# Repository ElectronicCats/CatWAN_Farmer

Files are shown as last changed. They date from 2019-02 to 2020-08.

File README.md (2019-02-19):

# CatWAN Farmer by Electronic Cats

CatWAN Farmer, a grower's water saving project

Monitoring soil moisture at different depths to determine when to irrigate, and - more importantly - how much water is needed. Save 25%!

## Main characteristics

- Provide low cost, easy to build, and rugged components for optimizing agricultural irrigation.
- DIY calibrated gypsum soil moisture sensors (Watermark SS200 is also supported).
- Hand held sensor reader (soil moisture, soil/water salinity, water pressure).
- Solar powered remote sensor platform.
- 4 electrically separated inputs for soil moisture sensors.
- LoRa module for long range (6 miles).
- temperature/humidity sensors.
- Solar battery charger.
- Real time clock for sleep mode power saving and precise irrigation timing.
- Gateway to connect multiple LoRa end nodes to the Internet.
- Supports packet mode LoRa® (package mode) or LoRaWAN ™ Class A, B and C.
- Compatible with Beelan, The Things Network and other LoRaWAN networks.
- Easy reprogramming compatible with Arduino and Circuit Python.

## Specifications

- 32-bit ARM Cortex-M0+ processor with 256KB flash, 32KB SRAM, and an operating speed of up to 48MHz. 
- Connectivity: USB 2.1.
- Vin: 4.2V-6.0V for charger - otherwise 3.5V-6.0V
- VBATT: 3.7V Lipo
- VCC: 600mA @3.3V
- Receiver Sensitivity: down to -146 dBm.
- TX Power: adjustable up to +18.5 dBm.
- Range: up to 15 km coverage in suburban and up to 5 km coverage.
- Watermark SS200 soil water tension sensor (4 x).
- Capacitive (FDR) volumetric soil moisture sensors (3x).
- Temperature and humidity.
- Compatible LoRa 915 and 868 Mhz.

## LICENSE

Hardware released under an CERN Open Hardware Licence v1.2. See the LICENSE_HARDWARE file for more information.

Designed by Electronic Cats.

Electronic Cats is a registered trademark, please do not use if you sell these PCBs.

Electronic Cats invests time and resources providing this open source design, please support Electronic Cats and open-source hardware by purchasing products from Electronic Cats!

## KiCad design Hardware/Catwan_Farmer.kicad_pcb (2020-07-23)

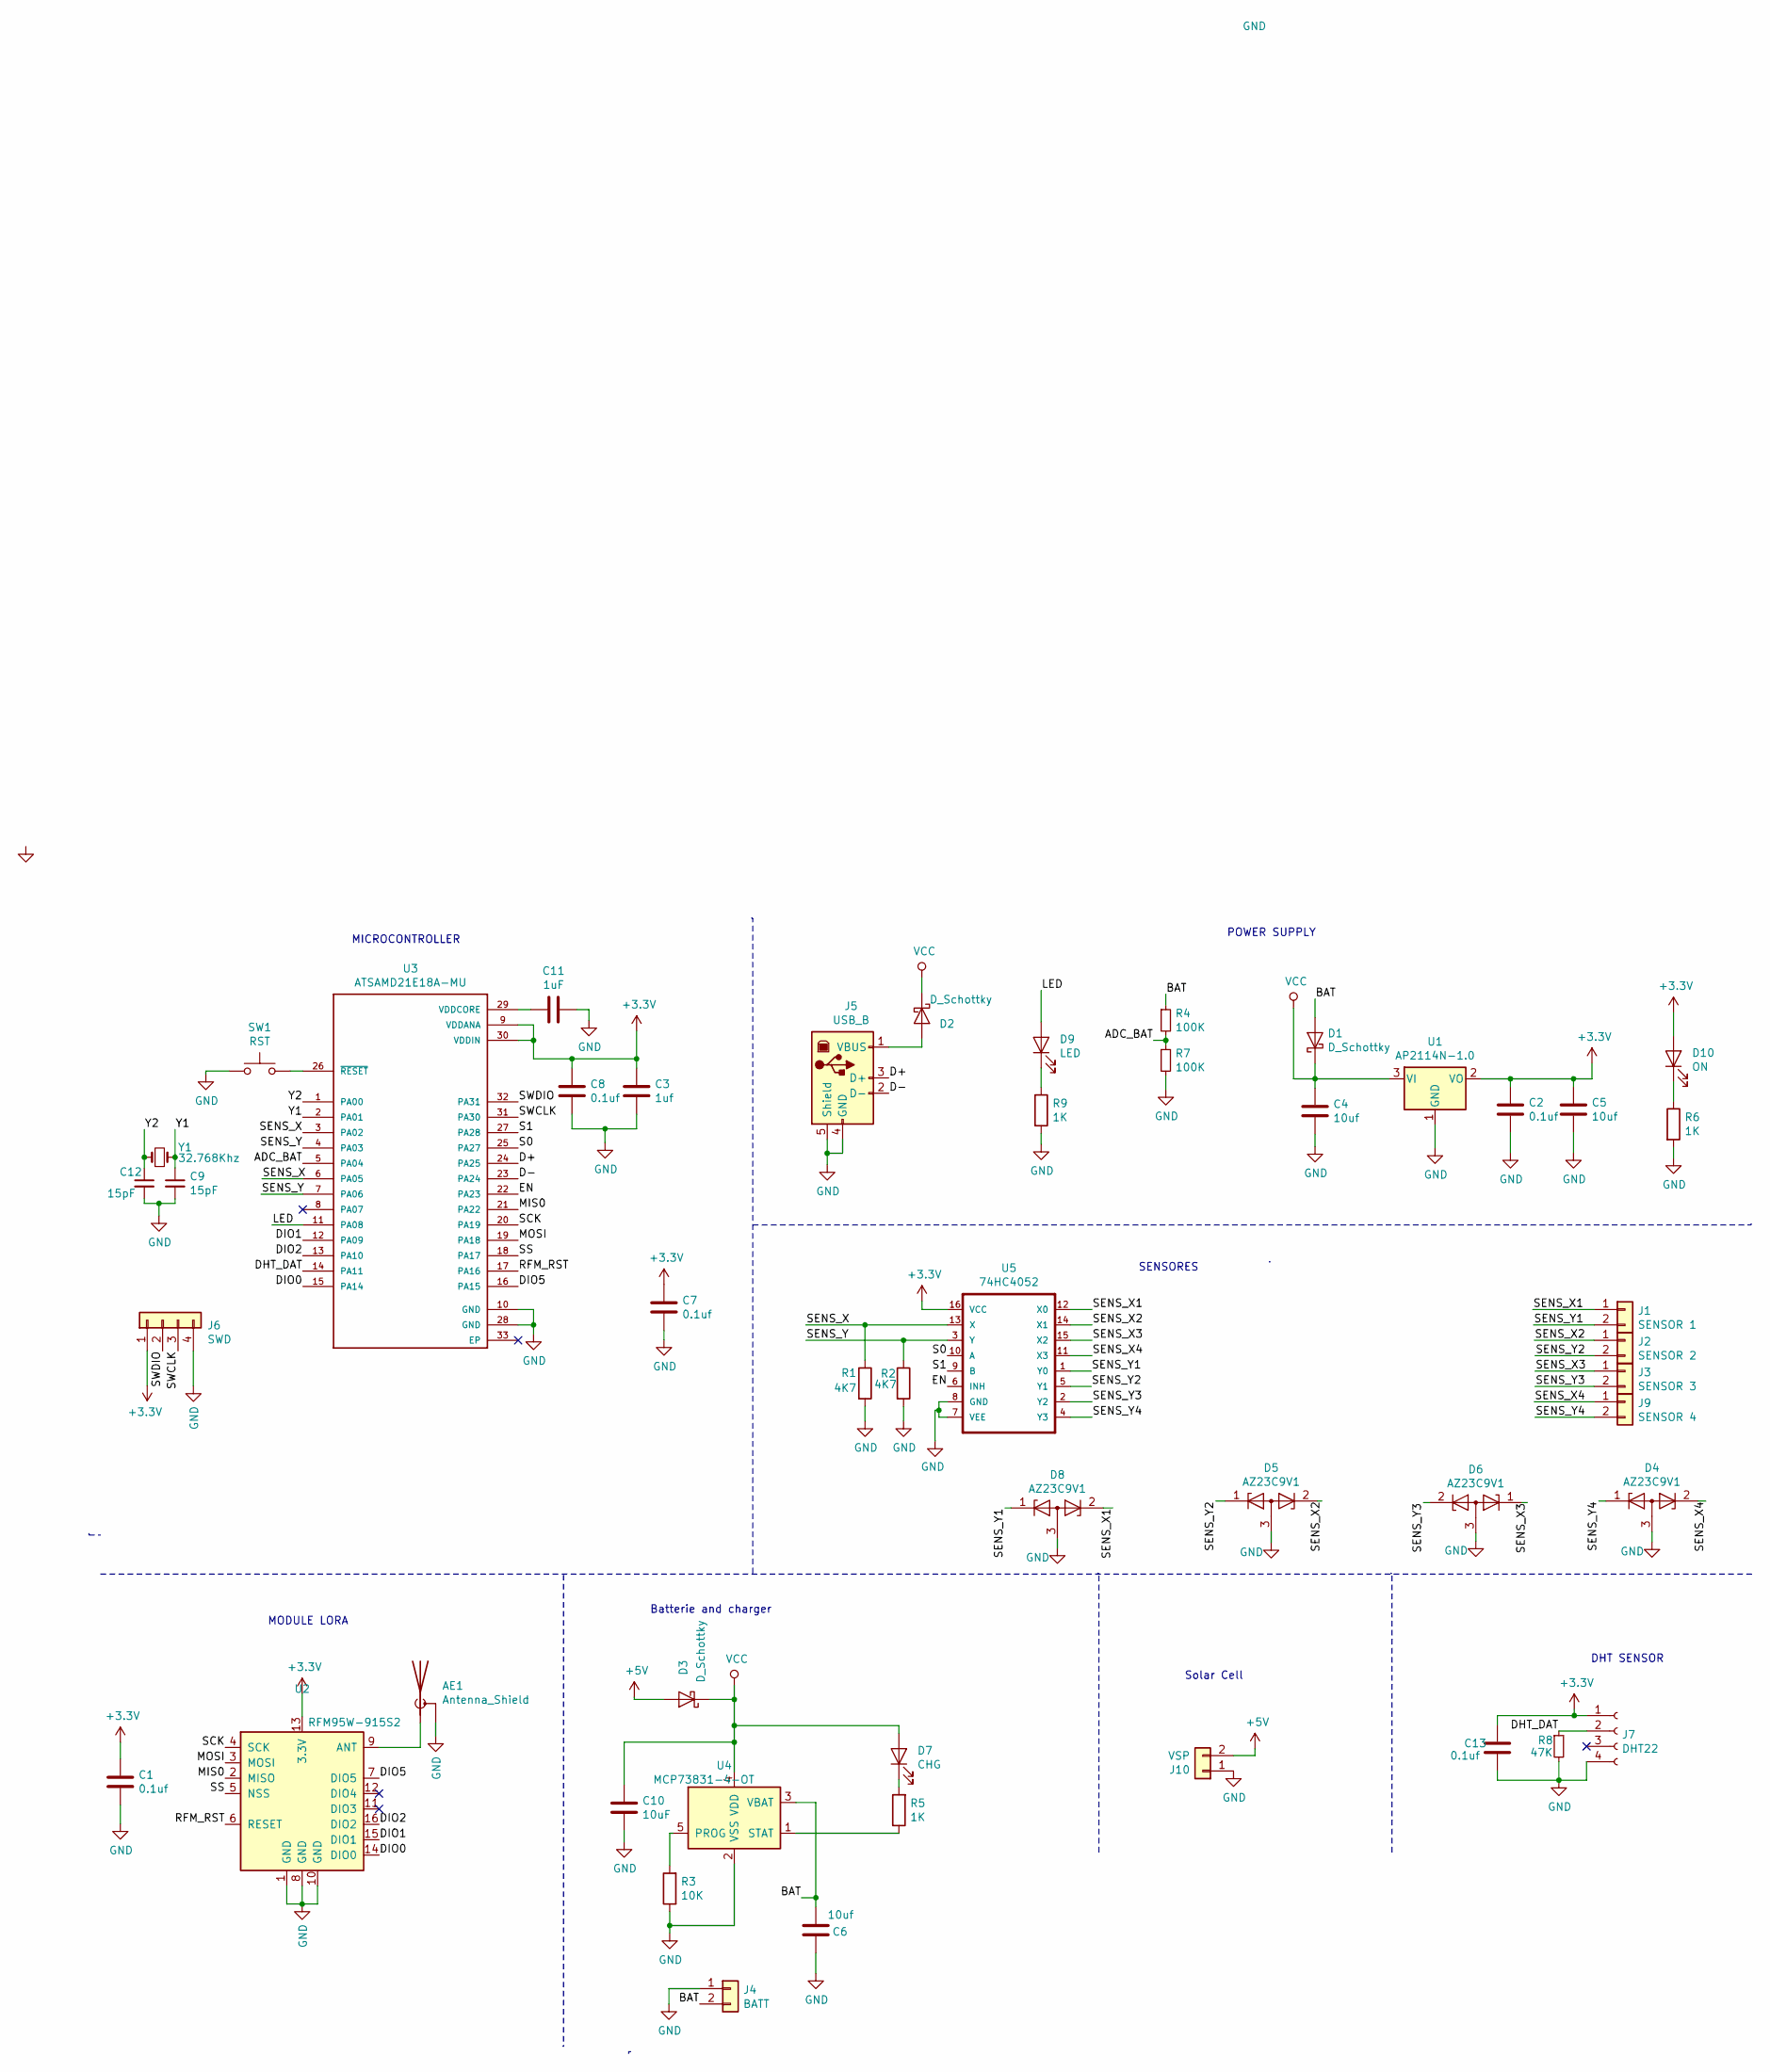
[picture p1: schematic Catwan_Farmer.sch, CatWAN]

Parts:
AE1: Antenna_Shield; AMPHENOL_901-144
C1, C2, C7, C8, C13: 0.1uf; C_0805_2012Metric_Pad1.15x1.40mm_HandSolder
C3: 1uf; C_0805_2012Metric_Pad1.15x1.40mm_HandSolder
C4, C5, C6: 10uf; C_0805_2012Metric_Pad1.15x1.40mm_HandSolder
C9, C12: 15pF; C_0805_2012Metric_Pad1.15x1.40mm_HandSolder
C10: 10uF; C_0805_2012Metric_Pad1.15x1.40mm_HandSolder
C11: 1uF; C_0805_2012Metric_Pad1.15x1.40mm_HandSolder
D1, D2, D3: D_Schottky; D_SOD-123
D4, D5, D6, D8: AZ23C9V1; SOT-23
D7: CHG; LED_0805_2012Metric_Pad1.15x1.40mm_HandSolder
D9: LED; LED_0805_2012Metric_Pad1.15x1.40mm_HandSolder
D10: ON; LED_0805_2012Metric_Pad1.15x1.40mm_HandSolder
J1: SENSOR 1; TerminalBlock_Phoenix_PT-1,5-2-3.5-H_1x02_P3.50mm_Horizontal
J2: SENSOR 2; TerminalBlock_Phoenix_PT-1,5-2-3.5-H_1x02_P3.50mm_Horizontal
J3: SENSOR 3; TerminalBlock_Phoenix_PT-1,5-2-3.5-H_1x02_P3.50mm_Horizontal
J4: BATT; TerminalBlock_Phoenix_PT-1,5-2-3.5-H_1x02_P3.50mm_Horizontal
J5: USB_B; U254051N4BH806
J6: SWD; PinHeader_1x04_P2.54mm_Vertical
J7: DHT22; PinHeader_1x04_P2.54mm_Vertical
J9: SENSOR 4; TerminalBlock_Phoenix_PT-1,5-2-3.5-H_1x02_P3.50mm_Horizontal
J10: VSP; TerminalBlock_Phoenix_PT-1,5-2-3.5-H_1x02_P3.50mm_Horizontal
R1, R2: 4K7; R_0805_2012Metric_Pad1.15x1.40mm_HandSolder
R3: 10K; R_0805_2012Metric_Pad1.15x1.40mm_HandSolder
R4, R7: 100K; R_0805_2012Metric_Pad1.15x1.40mm_HandSolder
R5, R6, R9: 1K; R_0805_2012Metric_Pad1.15x1.40mm_HandSolder
R8: 47K; R_0805_2012Metric_Pad1.15x1.40mm_HandSolder
SW1: RST; SW_SPST_SKQG_WithStem
U1: AP2114N-1.0; SOT-223-3_TabPin2
U2: RFM95W-915S2; HOPERF_RFM9XW_SMD
U3: ATSAMD21E18A-MU; TQFP-32_7x7mm_P0.8mm
U4: MCP73831-4-OT; SOT-23-5
U5: 74HC4052; SOIC-16_3.9x9.9mm_P1.27mm
Y1: 32.768Khz; Crystal_SMD_MicroCrystal_CC7V-T1A-2Pin_3.2x1.5mm_HandSolder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

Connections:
+3V3: C1.1, C2.1, C3.1, C5.1, C7.1, C8.1, C13.1, D10.2 (A), J6.1, J7.1, U1.2 (VO), U2.13 (3.3V), U3.9 (VDDANA), U3.30 (VDDIN), U5.16 (VCC)
+5V: D3.2 (A), J10.2
/ADC_BAT: R4.2, R7.1, U3.5 (PA04)
/BAT: C6.2, D1.2 (A), J4.2, R4.1, U4.3 (VBAT)
/D+: J5.3 (D+), U3.24 (PA25)
/D-: J5.2 (D-), U3.23 (PA24)
/DHT_DAT: J7.2, R8.1, U3.14 (PA11)
/DIO0: U2.14 (DIO0), U3.15 (PA14)
/DIO1: U2.15 (DIO1), U3.12 (PA09)
/DIO2: U2.16 (DIO2), U3.13 (PA10)
/DIO5: U2.7 (DIO5), U3.16 (PA15)
/EN: U3.22 (PA23), U5.6 (INH)
/LED: D9.2 (A), U3.11 (PA08)
/MIS0: U2.2 (MISO), U3.21 (PA22)
/MOSI: U2.3 (MOSI), U3.19 (PA18)
/RFM_RST: U2.6 (RESET), U3.17 (PA16)
/S0: U3.25 (PA27), U5.10 (A)
/S1: U3.27 (PA28), U5.9 (B)
/SCK: U2.4 (SCK), U3.20 (PA19)
/SENS_X: R1.1, U3.3 (PA02), U3.6 (PA05), U5.13 (X)
/SENS_X1: D8.2 (K), J1.1, U5.12 (X0)
/SENS_X2: D5.2 (K), J2.1, U5.14 (X1)
/SENS_X3: D6.1 (K), J3.1, U5.15 (X2)
/SENS_X4: D4.2 (K), J9.1, U5.11 (X3)
/SENS_Y: R2.1, U3.4 (PA03), U3.7 (PA06), U5.3 (Y)
/SENS_Y1: D8.1 (K), J1.2, U5.1 (Y0)
/SENS_Y2: D5.1 (K), J2.2, U5.5 (Y1)
/SENS_Y3: D6.2 (K), J3.2, U5.2 (Y2)
/SENS_Y4: D4.1 (K), J9.2, U5.4 (Y3)
/SS: U2.5 (NSS), U3.18 (PA17)
/SWCLK: J6.3, U3.31 (PA30)
/SWDIO: J6.2, U3.32 (PA31)
/Y1: C9.1, U3.2 (PA01), Y1.2
/Y2: C12.1, U3.1 (PA00), Y1.1
GND: AE1.2 (Shield), C1.2, C2.2, C3.2, C4.2, C5.2, C6.1, C7.2, C8.2, C9.2, C10.2, C11.1, C12.2, C13.2, D4.3 (A), D5.3 (A), D6.3 (A), D8.3 (A), J4.1, J5.4 (GND), J5.5 (Shield), J6.4, J7.4, J10.1, R1.2, R2.2, R3.1, R6.2, R7.2, R8.2, R9.2, SW1.1, U1.1 (GND), U2.1 (GND), U2.8 (GND), U2.10 (GND), U3.10 (GND), U3.28 (GND), U4.2 (VSS), U5.7 (VEE), U5.8 (GND)
unnamed: AE1.1 (A), U2.9 (ANT)
unnamed: C11.2, U3.29 (VDDCORE)
unnamed: D2.2 (A), J5.1 (VBUS)
unnamed: D7.1 (K), R5.2
unnamed: D9.1 (K), R9.1
unnamed: D10.1 (K), R6.1
unnamed: R3.2, U4.5 (PROG)
unnamed: R5.1, U4.1 (STAT)
unnamed: SW1.2, U3.26 (~RESET~)
VCC: C4.1, C10.1, D1.1 (K), D2.1 (K), D3.1 (K), D7.2 (A), U1.3 (VI), U4.4 (VDD)

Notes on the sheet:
MICROCONTROLLER
POWER SUPPLY
MODULE LORA
SENSORES
Solar Cell
DHT SENSOR
Batterie and charger

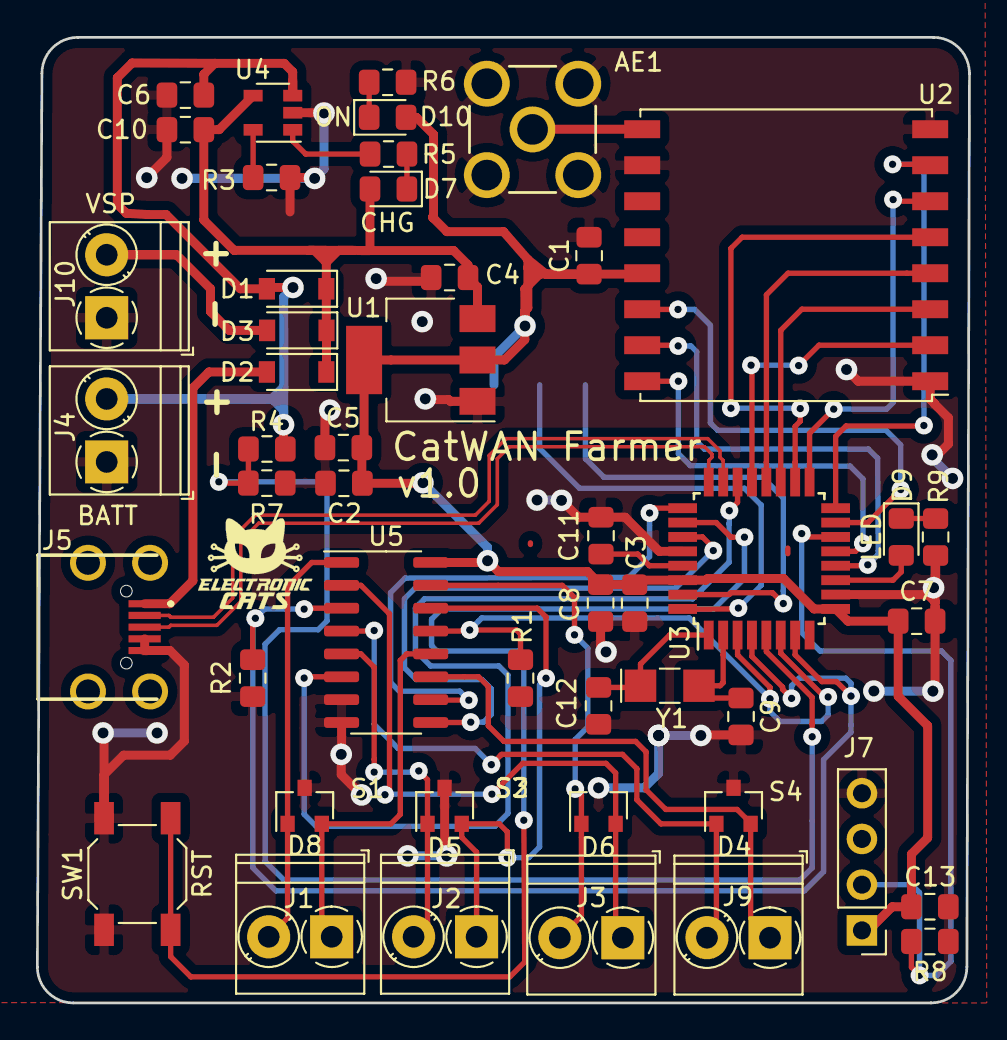
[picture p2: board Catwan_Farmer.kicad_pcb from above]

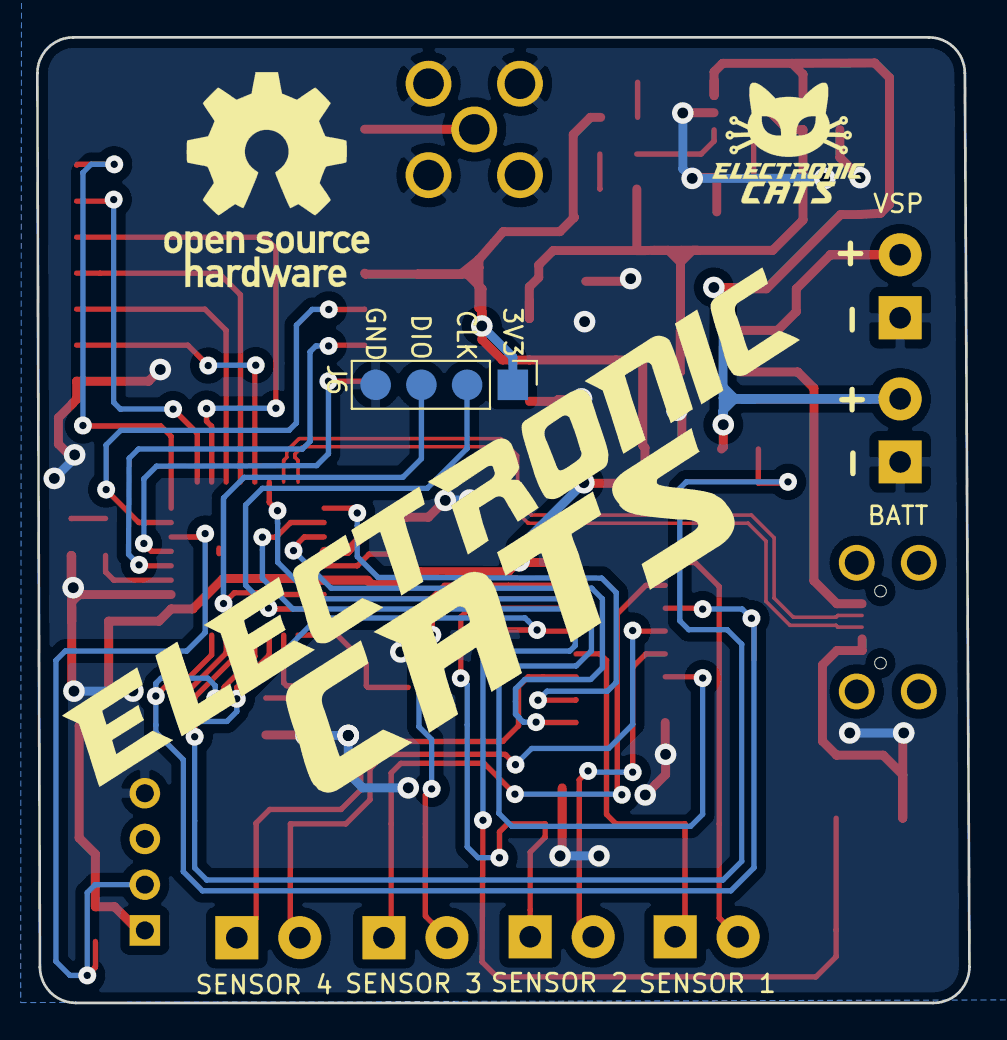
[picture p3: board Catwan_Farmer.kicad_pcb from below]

Board: 2 copper layers, 51.8 x 53.6 mm, 50 parts (2 on the bottom side), 45 nets.

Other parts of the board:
svg2mod: electronic; titule_electronic_med

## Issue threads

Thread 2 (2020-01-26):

TVS Diode footprint placement error?

aleibrecht, 2020-01-26:
Hi,

Could it be possible that TVS diode is using SOT footprint from a transistor Q# and that ground pin is misrouted?

Shouldn't the lone pad be connected to ground?

cheers

wero1414, 2020-01-28:
We had a mistake with the footprint assignation we are debbuging other possible mistakes done on the design so i hope this week we're solving all those mistakes

Closed 2020-02-09.

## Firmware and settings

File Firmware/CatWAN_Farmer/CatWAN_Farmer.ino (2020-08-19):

 /*******************************************************
  Firmware for CatWAN Farmer
  Andres Sabas @ Electronic Cats
  Montserrat Figueroa @ Electronic Cats

  Date Mar 28, 2019

  Based in the work of Reinier van der Lee, www.vanderleevineyard.com
  This code is beerware; if you see me (or any other Electronic Cats
  member) at the local, and you've found our code helpful,
  please buy us a round!
  Distributed as-is; no warranty is given.
*********************************************************/
#include <math.h>                 // Conversion equation from resistance to %

#include "DHT.h"
#include <lorawan.h>
/*
#include<CayenneLPP.h>

CayenneLPP lpp(51);
*/
#include "SAMD_AnalogCorrection.h"

#include <ArduinoLowPower.h>
int flag=true;


#define SENSOR0
//#define SENSOR1
#define SENSOR2
//#define SENSOR3

#define DEBUG
#define DEBUG2


typedef struct {        // Structure to be used in percentage and resistance values matrix to be filtered (have to be in pairs)
  int moisture;
  int resistencia;
} values;

// Setting up format for reading 4 soil sensors
#define NUM_READS 10   // Number of sensor reads for filtering

#define SENS_X 5
#define SENS_Y 6
#define ENABLE 23
#define S0 27
#define S1 28
#define ADC_BAT A2
#define DHTPIN 11
#define DHTTYPE DHT22

DHT dht(DHTPIN, DHTTYPE);
float tempC=24.0;

long WM0_Resistance,WM1_Resistance, WM2_Resistance,WM3_Resistance=0;
const long short_resistance=-20;
const long open_resistance=-100;
const long short_CB=240;
const long open_CB=255;
const long knownResistor = 4700;  // Value of R1 and R2 in Ohms, = reference for sensor

int supplyVoltage;      // Measured supply voltage
int sensorVoltage;      // Measured sensor voltage
int zeroCalibration = 95;        // calibrate sensor resistace to zero when input is short circuited
// basically this is compensating for the mux switch resistance

values valueOf[NUM_READS];        // Calculated  resistances to be averaged
long buffer[NUM_READS];
int indice=0;
int i;                            // Simple index variable
int j = 0;                        // Simple index variable


//ABP Credentials 
/*
const char *devAddr = "01 51 40 d0";
const char *nwkSKey = "84 92 6b c5 1b 7f 66 54 12 fb 6a 85 11 8c b3 aa";
const char *appSKey = "29 e1 ac 8f 2b 60 3f 18 75 f6 87 de 40 fa 22 ea";

const unsigned long interval = 10000;    // 10 s interval to send message
unsigned long previousMillis = 0;  // will store last time message sent
unsigned int counter = 0;     // message counter

char myStr[50];
char outStr[255];
byte recvStatus = 0;

const sRFM_pins RFM_pins = {
  .CS = 20,
  .RST = 9,
  .DIO0 = 0,
  .DIO1 = 1,
  .DIO2 = 2,
  .DIO5 = 15,
};
*/


void setup() 
{
  //analogReference(AR_EXTERNAL); // AR_EXTERNAL / AR_DEFAULT
  analogReadResolution(12);
 analogReadCorrection(9, 2069);

  
  // initialize serial communications at 9600 bps:
  Serial.begin(9600);             // initialize LoRa module communications
  while (!Serial) ; // Wait for Serial monitor to open

  // setting up the sensor interface
  // initialize digital pins D5, D6 as an high impedance input.
  // Pin 5,6 are f846r driving the soil moisture sensor
  pinMode(SENS_X, INPUT); // SENS_X
  pinMode(SENS_Y, INPUT); // SENS_Y
  // Pin 7 is for enabling Mux switches
  pinMode(ENABLE, OUTPUT); //ENABLE
  // Pin 8,9 are for selecting sensor 1-4
  pinMode(S0, OUTPUT);  // S0
  pinMode(S1, OUTPUT);  // S1

  Serial.println(F("DHT Init!"));
  dht.begin();

  pinMode(LED_BUILTIN, OUTPUT);
  #ifndef DEBUG
  // Uncomment this function if you wish to attach function dummy when RTC wakes up the chip
   LowPower.attachInterruptWakeup(RTC_ALARM_WAKEUP, lectura, CHANGE);
   #endif

/*
    if(!lora.init()){
    Serial.println("RFM95 not detected");
    delay(5000);
    return;
  }

  // Set LoRaWAN Class change CLASS_A or CLASS_C
  lora.setDeviceClass(CLASS_A);

  // Set Data Rate
  lora.setDataRate(SF8BW125);

  // set channel to random
  lora.setChannel(MULTI);
  
  // Put ABP Key and DevAddress here
  lora.setNwkSKey(nwkSKey);
  lora.setAppSKey(appSKey);
  lora.setDevAddr(devAddr);
*/
  
}

void loop()
{
  if(flag==true){
   temperatura();
   soilsensors();
//   printVariables();
   
   //float   cb0 = converter_cb(WM0_Resistance);
   //Serial.print("CB0:");
   //Serial.println(cb0);
   //float   cb1 = converter_cb(WM1_Resistance);
   //Serial.print("CB1:");
   //Serial.println(cb1);
   //float   cb2 = converter_cb(WM2_Resistance);
   //Serial.print("CB2:");
   //Serial.println(cb2);
   //float   cb3 = converter_cb(WM3_Resistance);
   //Serial.print("CB3:");
   //Serial.println(cb3);
   //envio();
  }
  
  // Triggers a 2000 ms sleep (the device will be woken up only by the registered wakeup sources and by internal RTC)
  // The power consumption of the chip will drop consistently
  #ifndef DEBUG
  LowPower.sleep(10000);
  #endif
/*
    // Check interval overflow
  if(millis() - previousMillis > interval) {
    previousMillis = millis(); 

    printVariables();

    Serial.print("Sending: ");
    lora.sendUplink((char *)lpp.getBuffer(), lpp.getSize(), 0, 1);
  }

  recvStatus = lora.readData(outStr);
  if(recvStatus) {
    Serial.println(outStr);
  }
  
  // Check Lora RX
  lora.update();
*/
  
}


/*
void printVariables()
{
  lpp.reset();

  int humidity = random(0,300);
  Serial.print(F(",humidity="));
  Serial.print(humidity, 1);
  lpp.addRelativeHumidity(3, humidity);

  int temp = random(0,200);
  Serial.print(F(",tempf="));
  Serial.print(temp, 1);
  lpp.addTemperature(4, temp);

  int batt_lvl = random(0,3.3);
  Serial.print(F(",batt_lvl="));
  Serial.print(batt_lvl, 2);
  lpp.addAnalogInput(8, batt_lvl);
}

*/

void lectura() 
{
 flag = true;
}

void temperatura()
{

  // Reading temperature or humidity takes about 250 milliseconds!
  // Sensor readings may also be up to 2 seconds 'old' (its a very slow sensor)
  float h = dht.readHumidity();
  // Read temperature as Celsius (the default)
  tempC = dht.readTemperature();

  // Check if any reads failed and exit early (to try again).
  if (isnan(h) || isnan(tempC)) {
    Serial.println(F("Failed to read from DHT sensor!"));
    return;
  }

  // Compute heat index in Celsius (isFahreheit = false)
  float hic = dht.computeHeatIndex(tempC, h, false);

  Serial.print(F("Humidity: "));
  Serial.print(h);
  Serial.print(F("%  Temperature: "));
  Serial.print(tempC);
  Serial.println(F("°C "));
}

void soilsensors() {

#ifdef SENSOR0
  //Select sensor 0, and enable MUX
  digitalWrite(S0, LOW);
  digitalWrite(S1, LOW);
  digitalWrite(ENABLE, LOW);
  measureSensor();
  WM0_Resistance = average();
#endif

#ifdef SENSOR1
  // Select sensor 1, and enable MUX
  digitalWrite(S0, LOW);
  digitalWrite(S1, HIGH);
  digitalWrite(ENABLE, LOW);
  measureSensor();
  WM1_Resistance = average();
#endif

#ifdef SENSOR2
  // Select sensor 2, and enable MUX
  digitalWrite(S0, HIGH);
  digitalWrite(S1, LOW);
  digitalWrite(ENABLE, LOW);
  delay(10);
  measureSensor();
  WM2_Resistance = average();
  
#endif

#ifdef SENSOR3
  // Select sensor 3, and enable MUX
  digitalWrite(S0, HIGH);
  digitalWrite(S1, HIGH);
  digitalWrite(ENABLE, LOW);
  measureSensor();
  WM3_Resistance = average();
#endif


  float Vsys = analogRead(ADC_BAT) * 0.00647; // read the battery voltage
  delay (50);


  //Print/send results
  Serial.print("Farmer");
  Serial.print(",");
#ifdef SENSOR0
  Serial.print("WM0_Resistance");
  Serial.println( WM0_Resistance);
  Serial.print(",");
#endif
#ifdef SENSOR1
  Serial.print("WM1_Resistance");
  Serial.print(WM1_Resistance);
  Serial.print(",");
#endif
#ifdef SENSOR2
  Serial.print("WM2_Resistance");
  Serial.println(WM2_Resistance);
  Serial.print(",");
#endif
#ifdef SENSOR3
  Serial.print("WM3_Resistance");
  Serial.print(WM3_Resistance);
  Serial.print(",");
#endif
  Serial.println(Vsys, 2);
  delay (5000);
}



void measureSensor()
{

  for (i = 0; i < NUM_READS; i++)
  {

    pinMode(SENS_X, OUTPUT);
    digitalWrite(SENS_X, HIGH);
    delayMicroseconds(25);
    sensorVoltage = analogRead(A1);   // read the sensor voltage
    supplyVoltage = analogRead(A0);   // read the supply voltage
    delayMicroseconds(25);
    digitalWrite(SENS_X, LOW);
    pinMode(SENS_X, INPUT);
    delay(100);
    long resistance = (knownResistor * (supplyVoltage - sensorVoltage ) / sensorVoltage) - zeroCalibration ;
    addReading(resistance);

#ifdef DEBUG2
    Serial.print("Resistor con: ");
    Serial.println(knownResistor);
    Serial.print("Supply V: ");
    Serial.println(supplyVoltage);
    Serial.print("Sensor V: ");
    Serial.println(sensorVoltage);
    Serial.print("Resistor: ");
    Serial.println(resistance);
#endif
    delay(1);

    pinMode(SENS_Y, OUTPUT);
    digitalWrite(SENS_Y, LOW);
    digitalWrite(SENS_Y, HIGH);
    delayMicroseconds(25);
    sensorVoltage = analogRead(A0);   // read the sensor voltage
    supplyVoltage = analogRead(A1);   // read the supply voltage
    delayMicroseconds(25);
    digitalWrite(SENS_Y, LOW);
    pinMode(SENS_Y, INPUT);

    resistance = (knownResistor * (supplyVoltage - sensorVoltage ) / sensorVoltage) - zeroCalibration ;
    delay(100);
    addReading(resistance);

#ifdef DEBUG2
    Serial.print("Resistor con: ");
    Serial.println(knownResistor);
    Serial.print("Supply V2: ");
    Serial.println(supplyVoltage);
    Serial.print("Sensor V2: ");
    Serial.println(sensorVoltage);
    Serial.print("Resistor2: ");
    Serial.println(resistance);
#endif


  }
}

// Averaging algorithm
void addReading(long resistance) {
  buffer[indice] = resistance;
  indice++;
  if (indice >= NUM_READS) indice = 0;
}

long average() {
  long sum = 0;
  for (int i = 0; i < NUM_READS; i++) {
    sum += buffer[i];
  }
  long promedio = (sum / NUM_READS);
  return promedio;
}

int converter_cb(float WM_Resistance )
{
   float WM_CB=0;
   Serial.println("WM_Resistance: ");
   Serial.println(WM_Resistance);
  //convert WM1 Reading to Centibars or KiloPascal
    // The trailing 00 for numbers are very critical in the formula below eg: 1 is written as 1.00, else code messes math due to int vs double for numbers
    if (WM_Resistance>550.00) 
    {
      if(WM_Resistance>8000.00)
      {
      WM_CB=-2.246-5.239*(WM_Resistance/1000.00)*(1+.018*(tempC-24.00))-.06756*(WM_Resistance/1000.00)*(WM_Resistance/1000.00)*((1.00+0.018*(tempC-24.00))*(1.00+0.018*(tempC-24.00))); 
      Serial.print("Entered WM1 >8000 Loop \n");
      } 
     if (WM_Resistance>1000.00) 
      {
        if (WM_Resistance<8000)
        {
     WM_CB=(-3.213*(WM_Resistance/1000.00)-4.093)/(1-0.009733*(WM_Resistance/1000.00)-0.01205*(tempC)) ;
     Serial.print("Entered WM1 >1000 Loop \n");
        }
      }
      if (WM_Resistance<1000.00)
        {
        if (WM_Resistance>550.00)
        {
        WM_CB=-20.00*((WM_Resistance/1000.00)*(1.00+0.018*(tempC-24.00))-0.55);
        Serial.print("Entered WM1>550 Loop \n");
        }
        }
     }
    if(WM_Resistance<550.00)
      {
        if(WM_Resistance>300.00)
        {
        WM_CB=0.00;
        Serial.print("Entered 550<WM1>0 Loop \n");
        }
        if(WM_Resistance<300.00)
        {
          if(WM_Resistance>=short_resistance)
          {   
          WM_CB=short_CB; //240 is a fault code for sensor terminal short
          Serial.print("Entered Sensor Short Loop WM1 \n");
          }
         
        }
        if(WM_Resistance<=open_resistance)
        {
        WM_CB=open_CB; //255 is a fault code for open circuit or sensor not present 
        Serial.print("Entered Open or Fault Loop for WM1 \n");
        }
      }
  return WM_CB;
}

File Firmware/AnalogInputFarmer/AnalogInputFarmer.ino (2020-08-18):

/*
  Analog Input

  Demonstrates analog input by reading an analog sensor on analog pin 0 and
  turning on and off a light emitting diode(LED) connected to digital pin 13.
  The amount of time the LED will be on and off depends on the value obtained
  by analogRead().

  The circuit:
  - potentiometer
    center pin of the potentiometer to the analog input 0
    one side pin (either one) to ground
    the other side pin to +5V
  - LED
    anode (long leg) attached to digital output 13
    cathode (short leg) attached to ground

  - Note: because most Arduinos have a built-in LED attached to pin 13 on the
    board, the LED is optional.

  created by David Cuartielles
  modified 30 Aug 2011
  By Tom Igoe

  This example code is in the public domain.

  http://www.arduino.cc/en/Tutorial/AnalogInput
*/

#include "SAMD_AnalogCorrection.h"

int sensorPin = A0
;    // select the input pin for the potentiometer
#define ENABLE 23
#define S0 27
#define S1 28
void setup() {
  analogReference(AR_EXTERNAL); // AR_EXTERNAL / AR_DEFAULT
  analogReadResolution(12);
  analogReadCorrection(38,2100);

  Serial.begin(9600);
    // Pin 7 is for enabling Mux switches
  pinMode(ENABLE, OUTPUT); //ENABLE
  // Pin 8,9 are for selecting sensor 1-4
  pinMode(S0, OUTPUT);  // S0
  pinMode(S1, OUTPUT);  // S1

  digitalWrite(S0, LOW);
  digitalWrite(S1, LOW);
  digitalWrite(ENABLE, LOW);
  delay(10);
}

void loop() {
  // read the value from the sensor:
  int sensorValue = analogRead(sensorPin);
  Serial.println(sensorValue);

  delay(500);
 
}

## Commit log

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2018-09-29 Agregue ATSAMD Y LORA
    [Catwan_sensorwater.sch]
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2018-10-02 SENSORES, MULTIPLEXOR
    [Catwan_sensorwater.sch]
2018-10-03 Multiplexor casi listo.
    [Catwan_sensorwater.sch]
2018-10-03 asignación huellas
    [Catwan_sensorwater.sch]
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2018-10-09 batería agregada.
    [Catwan_sensorwater.sch]
2018-10-10 huellas
    Cambios
    [Catwan_sensorwater.sch]
2018-10-25 add s0 s1 ans enable in multiplexer
    [Catwan_sensorwater.sch]
2018-10-25 Edit ATSAMD separate pin 10 and 28 an no connected
    [Catwan_sensorwater.sch]
2018-10-25 Capacitor VCC SAMD
    [Catwan_sensorwater.sch]
2018-10-26 Edit connections
    [Catwan_sensorwater.sch]
2018-10-26 Adjust of regulator
    [Catwan_sensorwater.sch]
2018-10-30 Connector ID
    [Catwan_sensorwater.sch]
2018-10-30 Fix
    Serial SWD
    [Catwan_sensorwater.sch]
2018-10-31 Pin modificado
    separados
    [Catwan_sensorwater.sch]
2018-10-31 Auto stash before merge of "master" and "origin/master"
    Change zener for MOSFET
    [Catwan_sensorwater.sch]
2018-10-31 add 3.3V to mux
    [Catwan_sensorwater.sch]
2018-10-31 Annotate no. MOSFET
    [Catwan_sensorwater.sch]
2018-10-31 ADD HUMIDITY SENSOR
    [Catwan_sensorwater.sch]
2018-11-01 Add 4 sensor
    [Catwan_sensorwater.sch]
2018-11-07 snapshot v0.3
    Update source to VCC, and check ERC
    [Catwan_sensorwater.sch]
2018-11-07 remove resistence for DHT22
    [Catwan_sensorwater.sch]
2018-11-12 Capacitor .1
    [Catwan_sensorwater.sch]
2018-11-13 Changes connections and error
    [Catwan_sensorwater.sch]
2018-11-13 Finished schematic
    [Catwan_sensorwater.sch]
2018-11-13 schematic modified
    [Catwan_sensorwater.sch]
2018-11-13 change pines j6
    [Catwan_sensorwater.kicad_pcb, Catwan_sensorwater.sch]
2018-11-13 Change j7
    [Catwan_sensorwater.sch]
2018-11-13 Inicio PCB
    [Catwan_sensorwater.kicad_pcb, Catwan_sensorwater.sch]
2018-11-17 Acomodo segunda parte
    [Catwan_sensorwater.kicad_pcb, Catwan_sensorwater.sch]
2018-11-20 Acomodo componentes
    [Catwan_sensorwater.kicad_pcb, Catwan_sensorwater.sch]
2018-11-22 Segunda parte
    [Catwan_sensorwater.kicad_pcb]
2018-11-22 distribution devices
    [Catwan_sensorwater.kicad_pcb]
2018-11-22 Change diodes
    [Catwan_sensorwater.sch]
2018-11-22 clear schematic
    [Catwan_sensorwater.sch]
2018-11-23 change pcb
    [Catwan_sensorwater.kicad_pcb, _saved_Catwan_sensorwater.sch]
2018-11-23 components back to the front
    [Catwan_sensorwater.kicad_pcb]
2018-11-23 diode shottkie and regulator packege
    [Catwan_sensorwater.kicad_pcb, _saved_Catwan_sensorwater.sch]
2018-11-24 new accommodation
    [Catwan_sensorwater.kicad_pcb, Catwan_sensorwater.sch]
2018-11-26 change label batt
    [Catwan_sensorwater.sch]
2018-11-26 pin read x and y
    [Catwan_sensorwater.sch, _saved_Catwan_sensorwater.sch]
2019-01-19 Rooteo new accommodation
    [Catwan_sensorwater.kicad_pcb]
2019-01-22 Rooteo GND
    [Catwan_sensorwater.kicad_pcb]
2019-01-23 Changes rooteo
    [Catwan_sensorwater.kicad_pcb]
2019-01-24 Microcontroller GND
    [Catwan_sensorwater.kicad_pcb]
2019-01-25 Changes GND
    [Catwan_sensorwater.kicad_pcb]
2019-01-25 Check rooteo
    [Catwan_sensorwater.kicad_pcb]
2019-01-25 Track correction
    [Catwan_sensorwater.kicad_pcb]
2019-01-28 Add diode and capacitor, food print assignment and list of networks
    [Catwan_sensorwater.sch]
2019-01-28 Adapter capacitor and diode
    [Catwan_sensorwater.kicad_pcb]
2019-01-29 Change food print microcontroller
    [Catwan_sensorwater.sch]
2019-01-29 Routeo changes with new footprint
    [Catwan_sensorwater.kicad_pcb]
2019-01-29 Add diodes in vsp, remove capacitor and 10k resistance
    [Catwan_sensorwater.sch]
2019-01-30 Add foodprint D3
    [Catwan_sensorwater.sch]
2019-02-05 Netlist D3
    [Catwan_sensorwater.kicad_pcb]
2019-02-08 changes foodprint diode
    [Catwan_sensorwater.sch]
2019-02-08 Add D3 PCB
    [Catwan_sensorwater.kicad_pcb]
2019-02-09 New routeo
    [Catwan_sensorwater.kicad_pcb]
2019-02-11 remove serial port
    [Catwan_sensorwater.sch]
2019-02-12 new netlist and accommodation
    [Catwan_sensorwater.kicad_pcb, Catwan_sensorwater.sch]
2019-02-20 Add logo and autors
    [Catwan_sensorwater.kicad_pcb]
2019-02-20 add RTC and ADC Battery
    [Catwan_sensorwater.kicad_pcb, Catwan_sensorwater.sch]
2019-02-21 New metlist add the components to the pcb and start of routeo
    [Catwan_sensorwater.kicad_pcb, Catwan_sensorwater.sch]
2019-02-21 move components
    [Catwan_sensorwater.kicad_pcb, _saved_Catwan_sensorwater.sch]
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2019-02-22 Routeo and ground plane
    [Catwan_sensorwater.kicad_pcb, _saved_Catwan_sensorwater.sch]
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2019-02-23 Update component placement and pot
    [Catwan_sensorwater.kicad_pcb]
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2019-04-17 add LED and sens voltage
    [Catwan_Farmer.sch]
2019-05-27 change mosfet to zenner
    [Catwan_Farmer.sch]
2020-01-14 update led, switch and labels
    [Catwan_Farmer.sch]
2020-01-17 Change sens_y analog pin
    [Catwan_Farmer.sch]
2020-01-17 No conect pin 8
    [Catwan_Farmer.sch]
2020-03-17 Fix multiplexor
    [Catwan_Farmer.sch]
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2020-03-24 fix c8 and c3
    [Catwan_Farmer.sch]
2020-03-25 add footprint crystal and value c8 and c3, fix footprint u3, u2 usb
    [Catwan_Farmer.kicad_pcb, Catwan_Farmer.sch]
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2020-06-06 Routeo new size pcb
    [Catwan_Farmer.kicad_pcb]
2020-06-11 Fix tracks samd
    [Catwan_Farmer.kicad_pcb]
2020-06-11 Change tracks D- D+
    [Catwan_Farmer.kicad_pcb]
2020-07-08 fix error pinout sensors
    [Catwan_Farmer.sch]
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2020-07-21 Change DI0 and CLK
    [Catwan_Farmer.kicad_pcb, Catwan_Farmer.sch]
2020-07-23 fix DHT and swd change r1 and r2
    [Catwan_Farmer.kicad_pcb]
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2020-08-19 correction adc
